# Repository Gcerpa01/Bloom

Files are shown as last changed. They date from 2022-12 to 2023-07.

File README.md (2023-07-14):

# Bloom
Current development of a BLE Application utilizing Swift UI. This app is meant to utilize the central manager to connect to an ESP32-C3 in order to control a strip of WS2812B lights alongside an ESP32 Devkit V1 and PCM5102.

# General Information
This project has been in the making for three years as an introduction to Arduino Microcontrollers, Bluetooth Low Energy, and Swift. We utilize the Bloom app in order to tell the ESP which mode we want the microcontroller to be in so that the lights display the desired animation. When in audio visualizer, we connect our audio source to an attached bluetooth receiver (ESP32 + PCM5102) to read the audio and the MSGEQ7 then divides the audio frequencies for the ESP32-C3 to create an audio visualizer using the connected LED lights. Additionally, we take use of the PCM5102's output jack to connect an external speaker to listen to the audio being played. 

# Demo
Demo (https://youtu.be/ml52ldNw_ss)

A timeline of my improvements and steps in this journey can be found [in this twitter thread] (https://twitter.com/PunaticGerry/status/1292268597901811712?s=20) as well as in this github repro.
**further information will be provided below**.
 
 ---
 ## Steps and Resources
  After having finished my [Blynk Audio Visualizer project](https://github.com/Gcerpa01/Blynk-Audio-Visualizer) I began to hit some issues during setup due to certain WiFis being locked by an additional user account(University Campus WiFi for instance), so I began to look for tutorials on utilizing BLE to control the arduino's mode as I would no longer to depend on any external factor besides the user's source device to communicate with the BLE module
  
### 1. Utilizing BLE

 #### Upgrading to ESP32-C3
 In an effort to make the circuit smaller as well as cheaper and more efficient, I moved over to an ESP32-C3. Rather than needing an Arduino Nano and an HM-10 module, we now only require 1 module, allowing us to have more memory for more commands and customization within our BLE app. The following tutorial proved useful in making this change:
1. [Random Nerds](https://randomnerdtutorials.com/esp32-bluetooth-low-energy-ble-arduino-ide/)

 #### Using an HM-10 Module
 I first began by following the following tutorials to learn how to communicate with an HM-10 BLE Module utilizing apps available in the app store such as LightBlue and BLE Scanner to communicate with the Arduino:
1. [Makers Portal](https://makersportal.com/blog/2019/10/14/bluetooth-module-with-arduino)
2. [Instructables](https://www.instructables.com/WS2812-controlled-with-Bluetooth-and-Arduino)
 
The finished code for the Arduino side can be found in the [**BLE_Arduino**](https://github.com/Gcerpa01/Bloom/tree/main/BLE_Arduino) folder. Please note that the color wheel feature is not compatible when using the HM-10 Module.
 
### 2. Communicating via an App
 Once I finished being able to communicate with the Arduino I then began to look for tutorials on writing BLE applications on iOS. The ones I found helpful were the following:
1. [Adafruit](https://learn.adafruit.com/build-a-bluetooth-app-using-swift-5/communication)
2. [JaredWolff](https://www.jaredwolff.com/the-ultimate-how-to-bluetooth-swift-with-hardware-in-20-minutes/)
3. [NovelBits Part 1](https://novelbits.io/intro-ble-mobile-development-ios/)
4. [NovelBits Part 2](https://novelbits.io/intro-ble-mobile-development-ios-part-2/)

 I do want to note that I ended up subscribing to NovelBits to follow their tutorial a bit more in depth in order to learn to properly connect and communicate with the HM-10 Module but I also added a few free tutorials I found online and listed them first in the list above.
 
Note: This step remained the same when moving to an ESP32-C3, witht the only changes requiring to change the UUID's of the device we are connecting to. 

### 3. Designing the App
 Once I got the fundamentals down, I then went into designing the application to both work and have a UI I myself am proud off and would think is user friendly. I actually started off from scratch in order to create proper Swift Views, Navigation, a Color Wheel(*Note: Not implemented yet on Arduino side*) and once the views were done, I then began implementing the functionality I learned in the previous step to have my UI have implemented functionality. I utilized the following tutorials in order to learn how to build the application:
 1. [Color Wheel - Priva 28](https://github.com/Priva28/SwiftUIColourWheel)
 2. [Custom Color Picker - Haipp](https://youtu.be/dPQM332JOWY)
 3. [Color Slider - Medium - Priva 28](https://priva28.medium.com/making-a-custom-slider-in-swiftui-db440cd6d88c)
 4. [The Complete Guide to NavigationView in SwiftUI - Paul Hudson](https://youtu.be/nA6Jo6YnL9g)
 5. [Building First SwiftUI App - Paul Hudson](https://www.youtube.com/watch?v=aP-SQXTtWhY)
 
 The art for the application was done using both available SF Symbols and Art I made(and am still working on). The files for the application can be found in the [**Bloom**](https://github.com/Gcerpa01/Bloom/tree/main/Bloom) and [**Bloom.xcodeproj**](https://github.com/Gcerpa01/Bloom/tree/main/Bloom.xcodeproj), requiring to have xcode in order to run the applications on your iOS device(currently not on the app store)
 
 ---
 # Schematic
  ## ESP32-C3
 As stated before, in an effort to modify the Arduino and HM-10 circuit, I switched over to an ESP32-C3 to have more memory and have less modules. Additionally, in sake of customizability I also utilized an additional ESP32 and PCM5102 in order to customize the bluetooth audio receiver by utilizing the [ESP32 A2DP Receiver Libaray](https://github.com/pschatzmann/ESP32-A2DP) allowing to create the receiver with an assigned name and output audio using the digital to audio converter chip(PCM5102) with it's included audio jack, while still being able to read the frequencies of the audio being played.
 
 Note: If music visualization is not desired, the ESP32,PCM5102,MSGEQ7 can be removed for a simple LED light controller
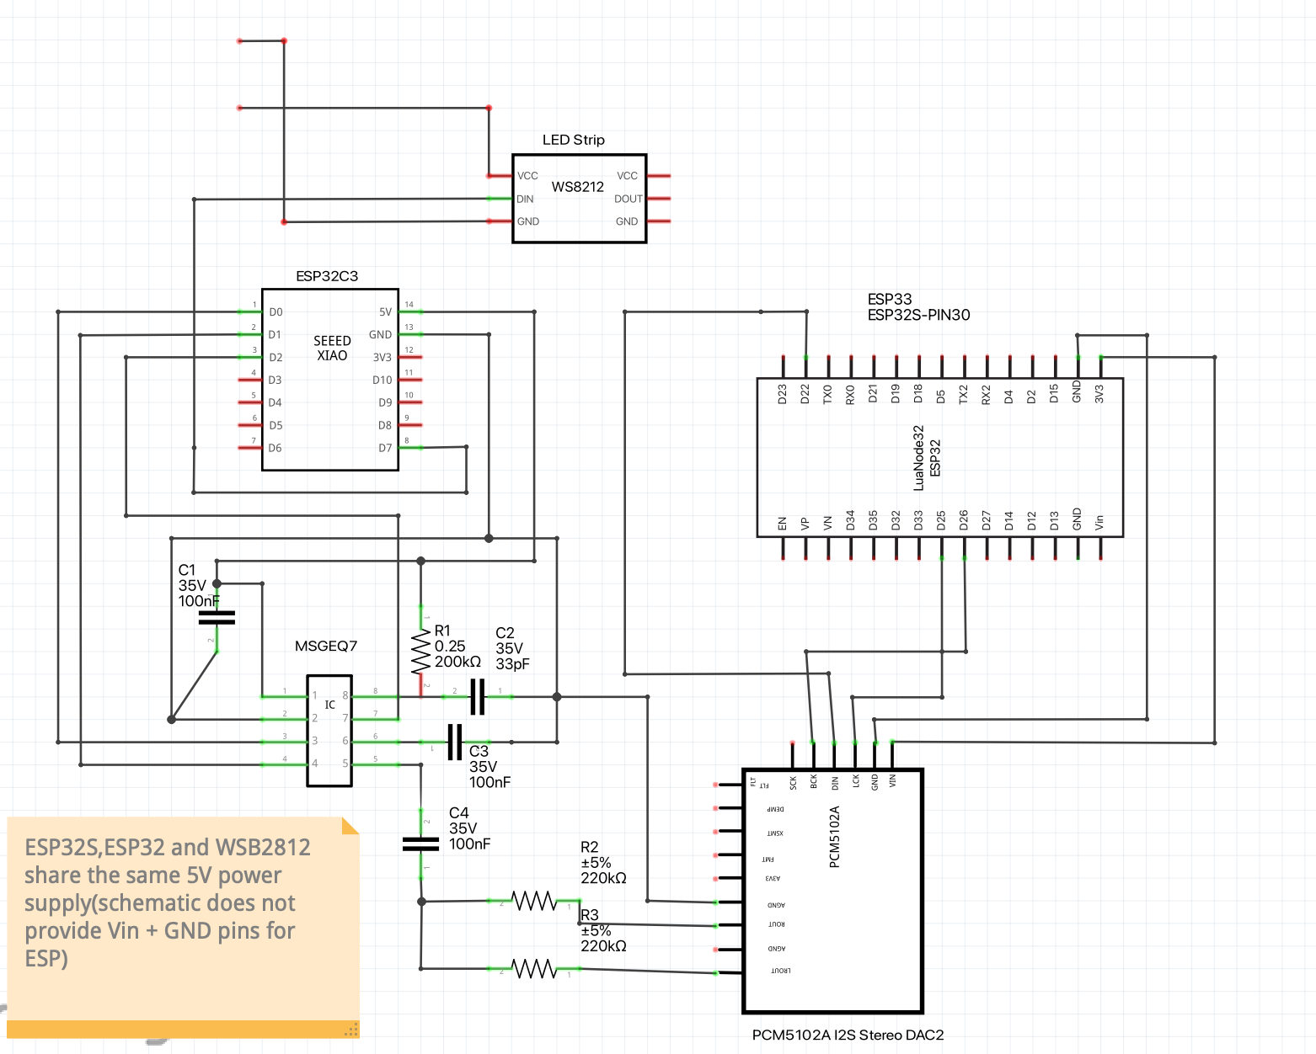
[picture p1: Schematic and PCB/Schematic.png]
New Modular
 
 
 ## Arduino and HM-10
For this project I modified my schematic from my [Blynk Audio Visualizer project](https://github.com/Gcerpa01/Blynk-Audio-Visualizer) to instead utilize an Arduino Nano and adding an HM-10 BLE module, with the final schematic appearing as below:

Untitled_Artwork

---
#### Caveats
 The project is at a point I'm happy calling it done despite it still needing a few upgrades. I need to work on some of the art for the buttons of the app, as well as enhance the code on the ESP32 side, as to have more animations avaiable in the app. Additionally, this code is exclusive to iOS at the moment given it was written for me and my family and friends to be able to utilize it so working on android alternative is a goal in the long run. 

---
#### Final Thoughts
 I began this project when I was in a dark spot in my life and I ended up finding a hobby I fell in love with. I have gone through multiple iterations for this project and despite it not being perfect it's at a state I am proud of what I have made and feel confident sharing it. I learned a lot about BLE, arduino, app development as well as coding but most importantly I learned about enjoying the journey and having fun with something. I do want to leave this repo updated and available as I want anyone learning or interested in learning these things to have access to this as a learning source.

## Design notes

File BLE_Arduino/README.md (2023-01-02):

# Bloom
Current development of a BLE Application utilizing Swift UI. This app is meant to utilize the central manager to connec to an HM-10 BLE module and an Arduino in order to control a strip of WS2812B lights

# General Information
This project has been in the making for two years as an introduction to Arduino Microcontrollers, Bluetooth Low Energy, and Swift. We utilize the Bloom app in order to tell the arduino which mode we want the microcontroller to be in so that the lights display the desired animation. When in audio visualizer, we connect our audio source to an attached bluetooth chip (MH-M28) to read the audio and the arduino then reads the audio frequencies to create an audio visualizer using the connected LED lights. Additionally, we take use of the MH-M28s' output jack to connect an external speaker to listen to the audio being played. 

A timeline of my improvements and steps in this journey can be found [in this twitter thread](https://twitter.com/PunaticGerry/status/1292268597901811712?s=20) and **further information will be provided below**.

 ***Videos of the final product can also be found in the twitter thread***
 
 ---
 ## Steps and Resources
  After having finished my [Blynk Audio Visualizer project](https://github.com/Gcerpa01/Blynk-Audio-Visualizer) I began to hit some issues during setup due to certain WiFis being locked by an additional user account(University Campus WiFi for instance), so I began to look for tutorials on utilizing BLE to control the arduino's mode as I would no longer to depend on any external factor besides the user's source device to communicate with the BLE module
  
### 1. Utilizing HM-10 Module
 I first began by following the following tutorials to learn how to communicate with an HM-10 BLE Module utilizing apps available in the app store such as LightBlue and BLE Scanner to communicate with the Arduino:
1. [Makers Portal](https://makersportal.com/blog/2019/10/14/bluetooth-module-with-arduino)
2. [Instructables](https://www.instructables.com/WS2812-controlled-with-Bluetooth-and-Arduino)
 
The finished code for the Arduino side can be found in the [**BLE_Arduino**](https://github.com/Gcerpa01/Bloom/tree/main/BLE_Arduino) folder 
 
### 2. Communicating via an App
 Once I finished being able to communicate with the Arduino I then began to look for tutorials on writing BLE applications on iOS. The ones I found helpful were the following:
1. [Adafruit](https://learn.adafruit.com/build-a-bluetooth-app-using-swift-5/communication)
2. [JaredWolff](https://www.jaredwolff.com/the-ultimate-how-to-bluetooth-swift-with-hardware-in-20-minutes/)
3. [NovelBits Part 1](https://novelbits.io/intro-ble-mobile-development-ios/)
4. [NovelBits Part 2](https://novelbits.io/intro-ble-mobile-development-ios-part-2/)

 I do want to note that I ended up subscribing to NovelBits to follow their tutorial a bit more in depth in order to learn to properly connect and communicate with the HM-10 Module but I also added a few free tutorials I found online and listed them first in the list above.

### 3. Designing the App
 Once I got the fundamentals down, I then went into designing the application to both work and have a UI I myself am proud off and would think is user friendly. I actually started off from scratch in order to create proper Swift Views, Navigation, a Color Wheel(*Note: Not implemented yet on Arduino side*) and once the views were done, I then began implementing the functionality I learned in the previous step to have my UI have implemented functionality. I utilized the following tutorials in order to learn how to build the application:
 1. [Color Wheel - Priva 28](https://github.com/Priva28/SwiftUIColourWheel)
 2. [Custom Color Picker - Haipp](https://youtu.be/dPQM332JOWY)
 3. [Color Slider - Medium - Priva 28](https://priva28.medium.com/making-a-custom-slider-in-swiftui-db440cd6d88c)
 4. [The Complete Guide to NavigationView in SwiftUI - Paul Hudson](https://youtu.be/nA6Jo6YnL9g)
 5. [Building First SwiftUI App - Paul Hudson](https://www.youtube.com/watch?v=aP-SQXTtWhY)
 
 The art for the application was done using both available SF Symbols and Art I made(and am still working on). The files for the application can be found in the [**Bloom**](https://github.com/Gcerpa01/Bloom/tree/main/Bloom) and [**Bloom.xcodeproj**](https://github.com/Gcerpa01/Bloom/tree/main/Bloom.xcodeproj), requiring to have xcode in order to run the applications on your iOS device(currently not on the app store)
 
 ---
 # Schematic
For this project I modified my schematic from my [Blynk Audio Visualizer project](https://github.com/Gcerpa01/Blynk-Audio-Visualizer) to instead utilize an Arduino Nano and adding an HM-10 BLE module, with the final schematic appearing as below:

Untitled_Artwork

---
#### Caveats
 The project is at a point I'm happy calling it done despite it still needing a few fixes. I need to work on some of the art for the buttons of the app, as well as enhance the code on the Arduino side, and perhaps switch to a different microcontroller as this code is currently unable to use all the animations I aimed for(hence them being grayed out via the application). Additionally, this code is exclusive to iOS at the moment given it was written for me and my family and friends to be able to utilize it so working on android alternative is a goal in the long run

---
#### Final Thoughts
 I began this project when I was in a dark spot in my life and I ended up finding a hobby I fell in love with. I have gone through multiple iterations for this project and despite it not being perfect it's at a state I am proud of what I have made and feel confident sharing it. I learned a lot about BLE, arduino, app development as well as coding but most importantly I learned about enjoying the journey and having fun with something. Hence even when I get the app on the app store I do want to leave this repo updated and available as I want anyone learning or interested in learning these things to have access to this as a learning source.

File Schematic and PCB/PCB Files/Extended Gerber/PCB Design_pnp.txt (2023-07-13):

*Pick And Place List
*Company=
*Author=
*eMail=
*
*Project=PCB Design
*Date=17:37:56
*CreatedBy=Fritzing 0.9.10b.2022-07-01.CD-2134-0-40d23c29
*
*
*Coordinates in mm, always center of component
*Origin 0/0=Lower left corner of PCB
*Rotation in degree (0-360, math. pos.)
*
*No;Value;Package;X;Y;Rotation;Side;Name
1;220k;THT;57.3159;-46.0543;90;Bottom;R2
2;;;28.1058;-6.68443;0;Bottom;Via23
3;;;79.6679;-22.9686;0;Top;GND1
4;100nF;100 mil [THT, multilayer];52.2359;-37.1643;-90;Bottom;C3
5;;;23.0258;-10.4944;0;Bottom;Via22
6;;;20.4858;-33.3543;0;Bottom;Via18
7;;;77.518;-39.8483;-90;Bottom;PCM5102A
8;100nF;100 mil [THT, multilayer];57.3159;-37.1643;-90;Bottom;C4
9;220k;THT;62.3959;-42.2443;90;Bottom;R3
10;200k;THT;42.0759;-37.1643;0;Bottom;R1
11;;;17.9458;-33.3543;0;Bottom;Via17
12;;;47.1558;-42.2443;0;Bottom;Via1
13;;;12.8658;-6.68443;0;Bottom;Via21
14;;;59.8558;-19.3844;0;Bottom;Via11
15;;;75.4935;-10.4875;90;Bottom;ESP32C3
16;;;34.4558;-9.22443;0;Bottom;Via9
17;;;31.9158;-33.3543;0;Bottom;Via7
18;;;9.05585;-11.7644;0;Bottom;Via3
19;;;59.8558;-27.0044;0;Bottom;Via10
20;;;24.2958;-51.1343;0;Bottom;Via16
21;;;34.4559;-5.41433;0;Top;Vin
22;;;17.9458;-51.1343;0;Bottom;Via15
23;;;40.8058;-11.7644;0;Bottom;Via19
24;;;73.4591;-22.9686;0;Top;Vin1
25;33pF;100 mil [THT, multilayer];44.6159;-39.7043;-180;Bottom;C2
26;;;14.8407;-26.6597;-90;Bottom;ESP32
27;;;36.9958;-16.8444;0;Bottom;Via2
28;100nF;100 mil [THT, multilayer];48.4259;-18.1143;0;Bottom;C1
29;;THT;50.9659;-28.2743;-90;Bottom;MSGEQ
30;;;36.9958;-1.60443;0;Bottom;Via20
31;;;30.6458;-23.1944;0;Bottom;Via14
32;;;45.6742;-54.3799;0;Top;Din
33;;;42.966;-54.3962;0;Top;Vin
34;;;38.2658;-20.6544;0;Bottom;Via12
35;;;40.8059;-5.41433;0;Top;GND
36;;;48.4258;-54.3799;0;Top;GND
37;;;40.8058;-23.1944;0;Bottom;Via13

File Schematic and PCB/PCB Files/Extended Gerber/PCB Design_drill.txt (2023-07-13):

; NON-PLATED HOLES START AT T1
; THROUGH (PLATED) HOLES START AT T100
M48
INCH
T100C0.038194
T101C0.030000
T102C0.038000
T103C0.035000
T104C0.015748
T105C0.035050
%
T100
X027871Y018838
X027871Y016877
X028065Y010131
X027871Y012877
X027871Y019877
X030065Y010131
X027871Y013877
X032065Y010131
X029065Y010131
X027871Y017877
X031065Y010131
X033064Y010131
X027871Y015877
X027871Y014878
X027871Y020878
T101
X017063Y015631
X022565Y015133
X022565Y014131
X020565Y015133
X019567Y007131
X020565Y014131
X018565Y007131
X018065Y015631
T102
X031565Y001131
X030565Y007136
X032565Y007136
X028565Y001131
X027565Y007136
X028565Y007136
X031565Y007136
X032565Y001131
X029565Y001131
X029565Y007136
X026565Y001131
X027565Y001131
X026565Y007136
X030565Y001131
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

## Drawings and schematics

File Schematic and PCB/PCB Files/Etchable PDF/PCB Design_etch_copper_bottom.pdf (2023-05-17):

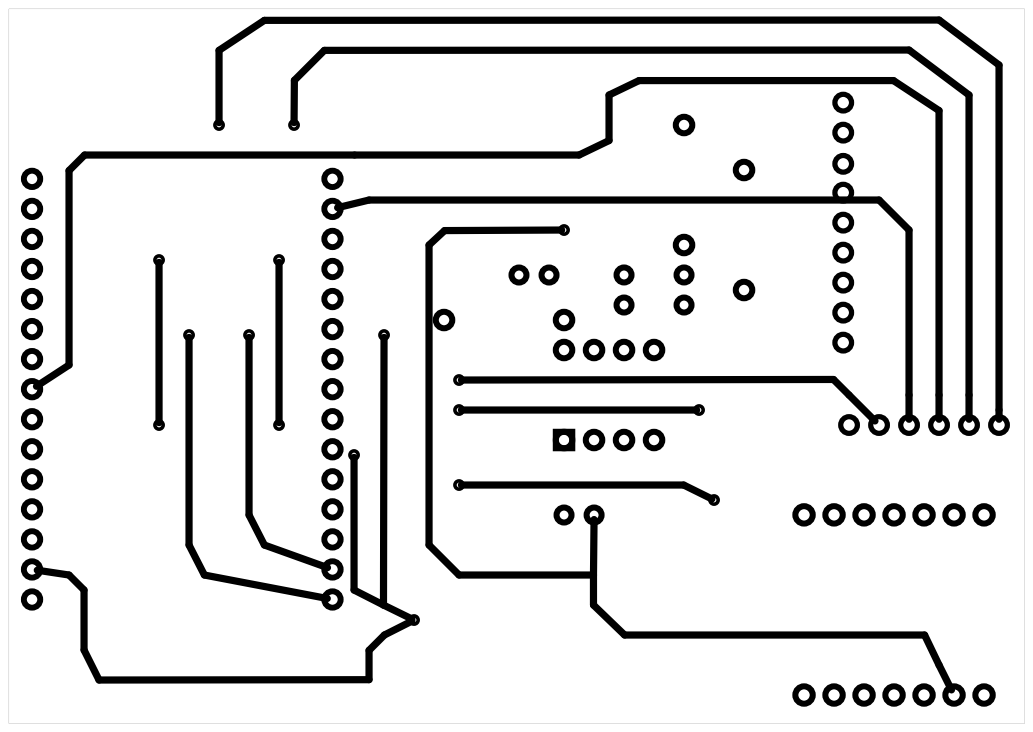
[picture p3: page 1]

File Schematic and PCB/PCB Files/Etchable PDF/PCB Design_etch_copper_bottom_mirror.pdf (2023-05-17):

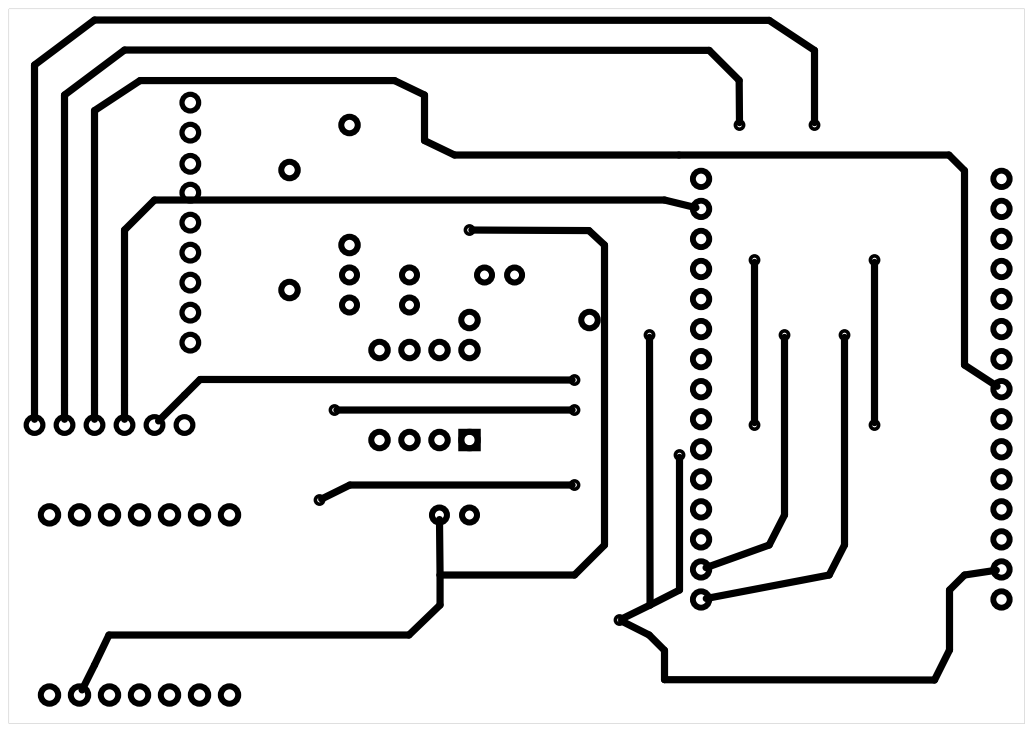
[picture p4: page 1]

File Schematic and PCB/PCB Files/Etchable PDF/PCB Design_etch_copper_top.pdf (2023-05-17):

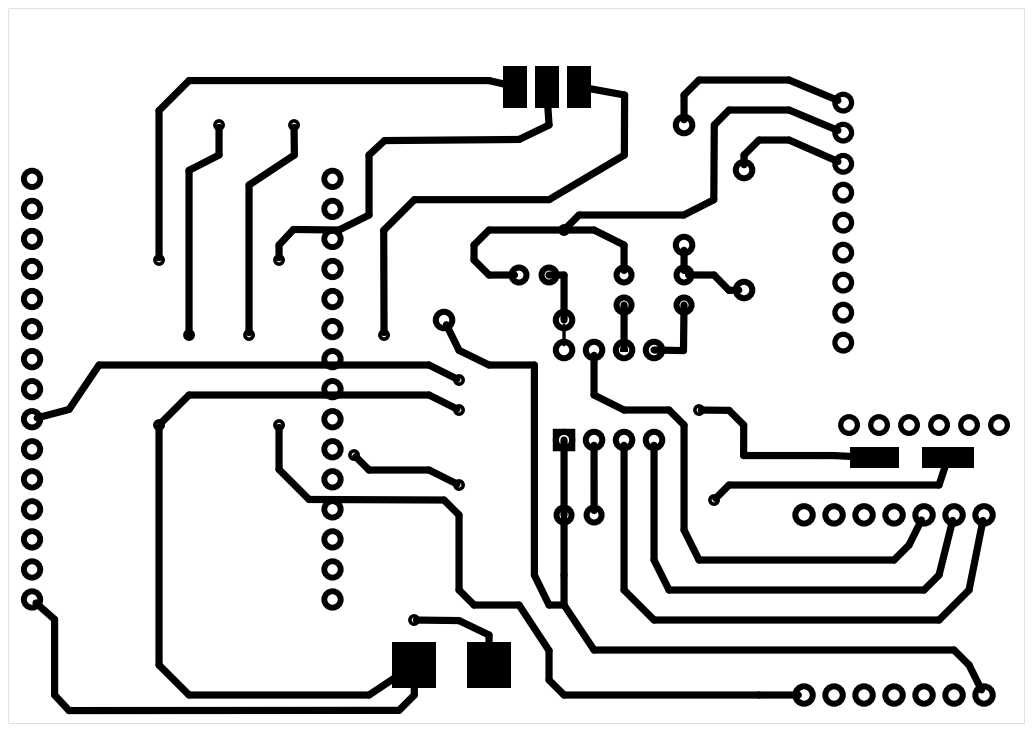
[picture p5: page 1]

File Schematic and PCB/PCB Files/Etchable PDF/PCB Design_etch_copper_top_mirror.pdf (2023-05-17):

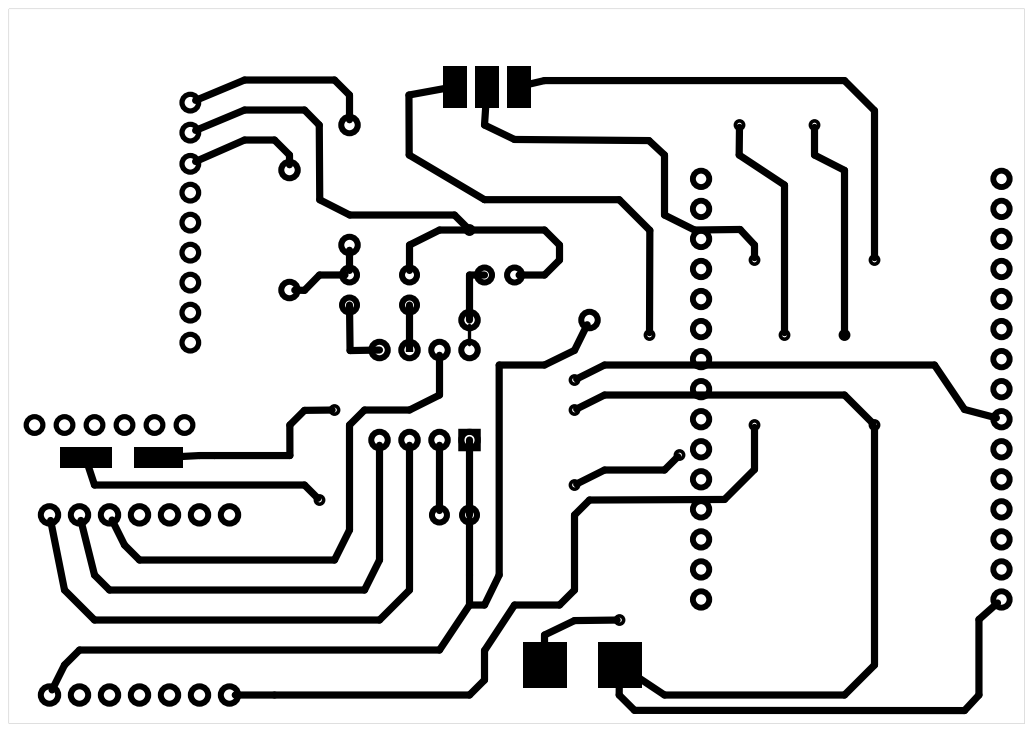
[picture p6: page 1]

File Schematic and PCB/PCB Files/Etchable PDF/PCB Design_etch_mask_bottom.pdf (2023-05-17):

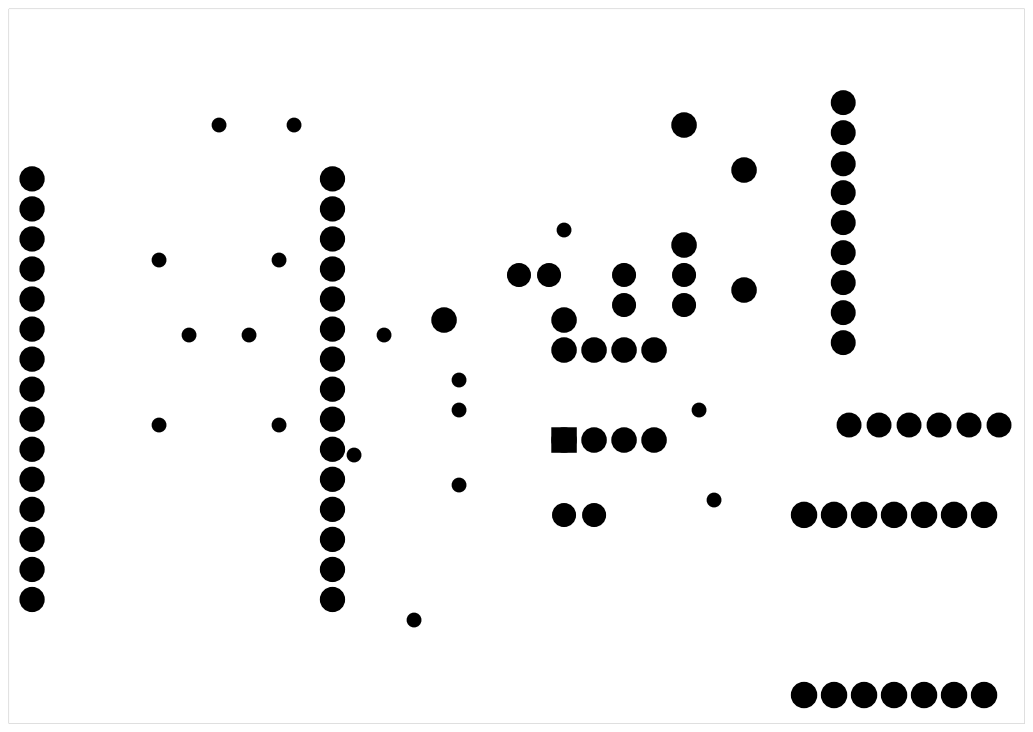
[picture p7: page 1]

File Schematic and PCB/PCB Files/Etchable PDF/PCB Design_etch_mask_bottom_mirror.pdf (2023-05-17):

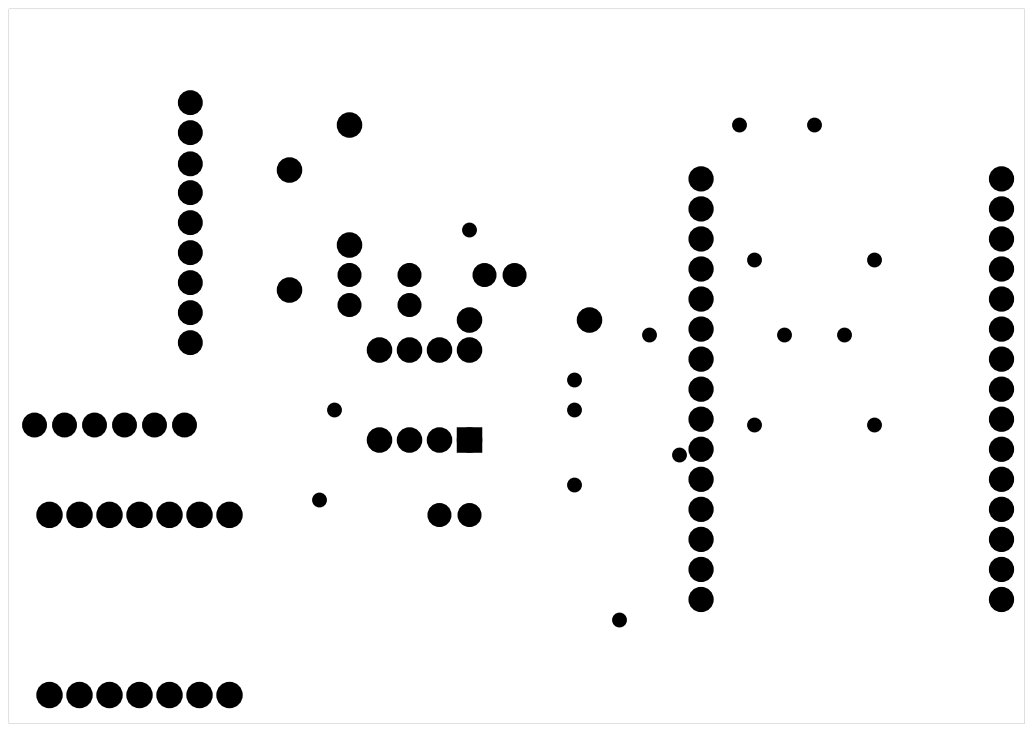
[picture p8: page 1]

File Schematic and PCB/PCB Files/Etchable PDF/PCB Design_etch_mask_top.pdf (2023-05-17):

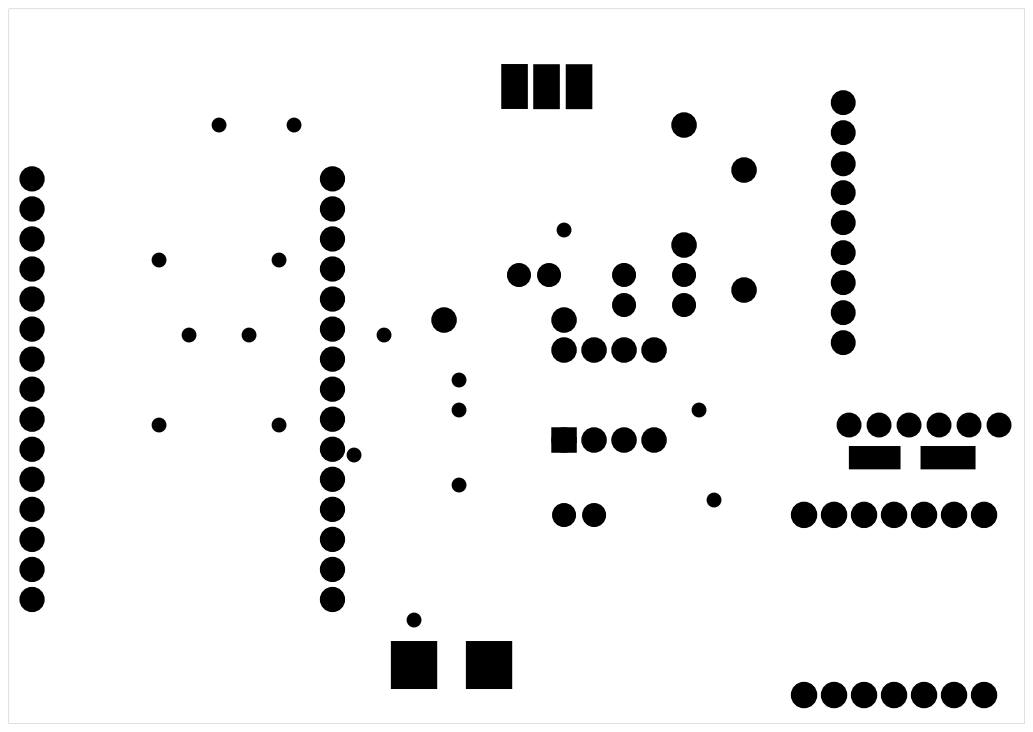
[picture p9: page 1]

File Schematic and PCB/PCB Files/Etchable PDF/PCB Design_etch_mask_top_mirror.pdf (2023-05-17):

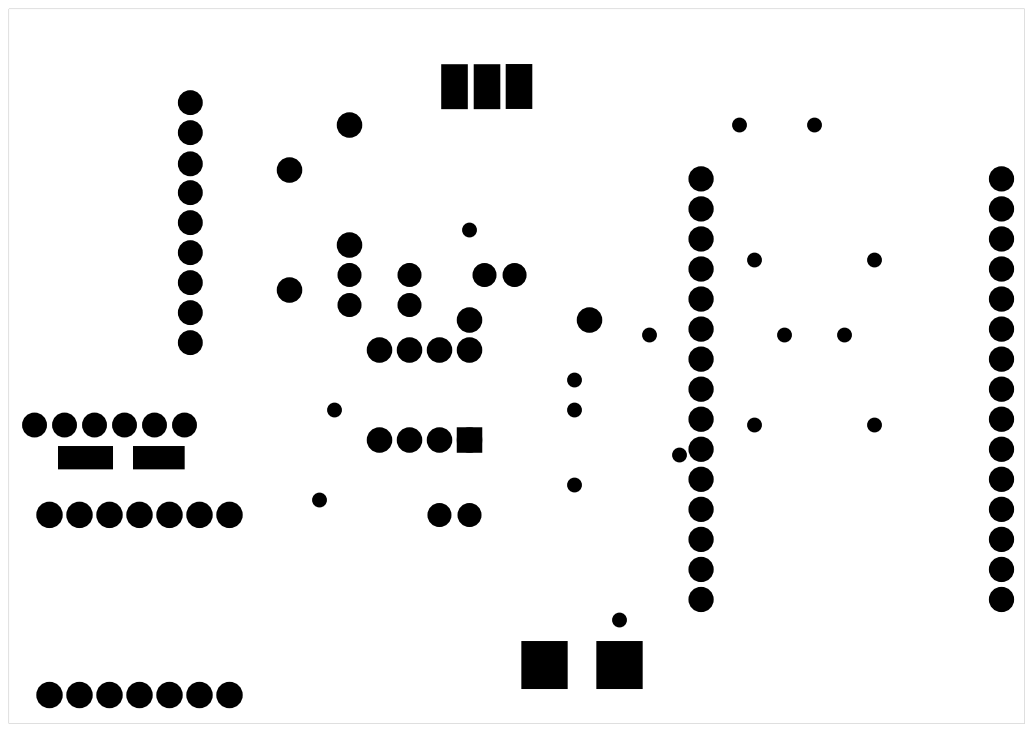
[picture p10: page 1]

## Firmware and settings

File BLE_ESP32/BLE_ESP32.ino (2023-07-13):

/* Gerardo Cerpa
 *
 * Utilized David Wang's code to read audio input from a 3.5 mm cable
 * so huge amount of gratitude to him.
 * The audio input is then used to animate an LED stip based
 * on the pitch and volume of the music.
 *
 *Also utilized Mark Wang's Pride 2015 animation, all credit goes to him
 *for that section of code and gratitude for an introduction
 *to LEDs
 *
 */

#include <FastLED.h>
#include "audioVisualizer.h"

/* -------------------------------- */
/*  ---------- BLE Control -------- */
/*  ------------------------------ */
#include <BLEDevice.h>
#include <BLEServer.h>
#include <BLEUtils.h>
#include <BLE2902.h>

char select_code[4] = "OFF";

/*  ------------------------------ */
/*  ------- Audio Visualizer ----- */
/*  ------------------------------ */
const int analogPin = A0; // MSGEQ7 OUT
const int strobePin = D1;  // MSGEQ7 STROBE 
const int resetPin = D2;   // MSGEQ7 RESET 
int spectrumValue[7];
// MSGEQ7 OUT pin produces values around 50-80
// when there is no input, so use this value to
// filter out a lot of the chaff.
int filterValue = 3000;
int brightness = 50;

/* -------------------------------- */
/*  ------- Control Variables ----- */
/*  ------------------------------ */
// Control variables to help dictate the mode running
int lightStatus = 0;
int colorWheelValues[3];
// Create led object
Color led;

/* -------------------------------- */
/*  ------- BLE Characteristics ----- */
/*  ------------------------------ */
BLEServer *pServer;
BLECharacteristic *pCharacteristic;

bool deviceConnected = false;
bool connectTimer = false;
unsigned long currentMillis, prevMillis = 0;
#define SERVICE_UUID "f56d1221-e24d-4b61-bbb6-cb8929f3a63b" // UART service UUID
#define LED_MODES_UUID "49360c8a-37b2-4fb8-b7f5-9957cb972fbc"
#define CHARACTERISTIC_UUID_TX "7afe65ae-976c-4a3a-84c1-8c33984019b7"
#define COLOR_WHEEL_UUID "325d04af-b205-4b96-a656-4ca6547159c8"

class MyServerCallbacks : public BLEServerCallbacks
{
 void onConnect(BLEServer *pServer)
 {
   if (!deviceConnected)
   {
     prevMillis = millis();
     connectTimer = true;
     Serial.println("Timer started to connect");
   }
   else
   {
     Serial.println("a device is already paired");
     ESP.restart();
   }
 };

 void onDisconnect(BLEServer *pServer)
 {
   deviceConnected = false;
   Serial.println("Device is not connected");
   pServer->startAdvertising(); // restart advertising after disconnecting
 }
};

class ControllerCallbacks : public BLECharacteristicCallbacks
{
 void onWrite(BLECharacteristic *pCharacteristic)
 {
   std::string commandReceived = pCharacteristic->getValue();

   if (commandReceived.length() > 0)
   {
     Serial.println("*********");
     Serial.print("Received Value: ");
     for (int i = 0; i < commandReceived.length(); i++)
     {
       Serial.print(commandReceived[i]);
     }
     Serial.println();

     if (!deviceConnected)
     {
       if (commandReceived.find("CC") != -1)
       {
         deviceConnected = true;
         connectTimer = false;
         Serial.println("Successfully paired");
       }
       else Serial.println("Incorrect");
     }
     else
     {

       // Do stuff based on the command received from the app
       if (commandReceived.find("OFF") != -1)
       {
         lightStatus = 0;
       }
       else if (commandReceived.find("WAV") != -1)
       {
         lightStatus = 1;
       }

       else if (commandReceived.find("PRD") != -1)
       {
         lightStatus = 2;
       }

       else if (commandReceived.find("SA1") != -1)
       {
         lightStatus = 3;
       }
     }

     Serial.println();
     Serial.println("*********");
   }
 }
};

class ColorWheelCallbacks : public BLECharacteristicCallbacks
{
 void onWrite(BLECharacteristic *pCharacteristic)
 {
   std::string commandReceived = pCharacteristic->getValue();
   if (deviceConnected)
   {
     lightStatus = 4;
     if (commandReceived.length() > 0)
     {
       Serial.println("*********");
       Serial.print("Received Value: ");
       for (int i = 0; i < commandReceived.length(); i++)
       {
         Serial.print(commandReceived[i]);
       }

       size_t string_pos = 0;
       size_t num_value = 0;
       while ((string_pos = commandReceived.find(",")) != std::string::npos)
       {
         colorWheelValues[num_value] = stoi(commandReceived.substr(0, string_pos));
         num_value += 1;
         commandReceived.erase(0, string_pos + 1);
       }

       colorWheelValues[2] = stoi(commandReceived.substr(0, string_pos));
//
//       Serial.print("Setting lights to ");
//       Serial.print(colorWheelValues[0]);
//       Serial.print(", ");
//       Serial.print(colorWheelValues[1]);
//       Serial.print(", ");
//       Serial.print(colorWheelValues[2]);
//       Serial.println(".");
     }
   }
   else
     Serial.println("Can't use,not connected");
 }
};

void setup()
{
  Serial.begin(9600);
  delay(100);

 // Create the BLE Device
 BLEDevice::init("Bloom"); // Give it a name

 // Create the BLE Server
 BLEServer *pServer = BLEDevice::createServer();
 pServer->setCallbacks(new MyServerCallbacks());

 // Create the BLE Service
 BLEService *pService = pServer->createService(SERVICE_UUID);

 // Create a BLE Characteristic
 pCharacteristic = pService->createCharacteristic(
     CHARACTERISTIC_UUID_TX,
     BLECharacteristic::PROPERTY_NOTIFY);

 pCharacteristic->addDescriptor(new BLE2902());

 BLECharacteristic *pCharacteristic = pService->createCharacteristic(
     LED_MODES_UUID,
     BLECharacteristic::PROPERTY_WRITE);

 BLECharacteristic *pCharacteristic2 = pService->createCharacteristic(
     COLOR_WHEEL_UUID,
     BLECharacteristic::PROPERTY_WRITE);

 pCharacteristic->setCallbacks(new ControllerCallbacks());
 pCharacteristic2->setCallbacks(new ColorWheelCallbacks());

 // Start the service
 pService->start();

 // Start advertising
 pServer->getAdvertising()->start();
 Serial.println("Waiting a client connection to notify...");

  /*  ------------------------------ */
  /*  -------- Set Up LEDS --------- */
  /*  ------------------------------ */
  led.ledSetup();

  /*  ------------------------------ */
  /*  ---- LED Visualizer Setup ---- */
  /*  ------------------------------ */
  // Setup the pins for reading from MSGEQ7
  randomSeed(analogRead(A0));
  // Read from MSGEQ7 OUT
  pinMode(analogPin, INPUT);
  // Write to MSGEQ7 STROBE and RESET
  pinMode(strobePin, OUTPUT);
  pinMode(resetPin, OUTPUT);
  // Set analogPin's reference voltage
  // analogReference(DEFAULT); // 5V

  // Set startup values for pins
  digitalWrite(resetPin, LOW);
  digitalWrite(strobePin, HIGH);
}

// Create an array of different methods to dictate the mode that will be
// running with the program
typedef void (*Spectremodes[])();
Spectremodes pos = {off, audio, pride, sparkle_AudioI, colorPicker};

void loop()
{
 if (connectTimer)
 {
   currentMillis = millis();
   if (currentMillis - prevMillis >= 9000)
   {
     Serial.println("Do not connect device");
     connectTimer = false;
     ESP.restart();
   }
 }
 if (deviceConnected)
 {
   pCharacteristic->setValue("Connected");
   pCharacteristic->notify();
 }
  pos[lightStatus]();
  // put your main code here, to run repeatedly:
}

// Runs the audio visualizer function to display
// an audio spectrum across the lights
void audio()
{
  Serial.println("AVI");

  digitalWrite(resetPin, HIGH);
  digitalWrite(resetPin, LOW);
  // Get all 7 spectrum values from the MSGEQ7
  for (int i = 0; i < 7; i++)
  {
    digitalWrite(strobePin, LOW);
    delayMicroseconds(30); // Allow output to settle

    spectrumValue[i] = analogRead(analogPin);

    // Constrain any value above 1023 or below filterValue
    spectrumValue[i] = constrain(spectrumValue[i], filterValue, 4000);

    // Remap the value to a number between 0 and 255
    spectrumValue[i] = map(spectrumValue[i], filterValue, 4000, 0, 255);

    // Remove serial stuff after debugging
//     Serial.print(spectrumValue[i]);
//     Serial.print(" ");
    digitalWrite(strobePin, HIGH);
  }
//  // Serial.println(""
  Color audioLights;
  audioLights.animate(spectrumValue);
}

// Turns all leds off
void off()
{
  Serial.println("Off");

  do
  {                                    // Start of a loop
    brightness = brightness - 10;      // Subtract 10 from the bright variable and save it
    FastLED.setBrightness(brightness); // Set LED strip Brightness to the value storged in "Bright"
    FastLED.show();                    // Update LED strip
    delay(10);                         // Wait for 10ms
  } while (brightness > 0);            // Go back to start of the loop if Bight is bigger then 0
  FastLED.clear();
  brightness = 50; // turn of LED strip
  FastLED.setBrightness(brightness);
  FastLED.show();
}

// Changes animation to sample provided in FastLED library
void pride()
{
  Color pride;
  pride.pridefx();
  Serial.println("Pride is on");
  FastLED.setBrightness(brightness);
  FastLED.show();
}

void sparkle_AudioI()
{
  digitalWrite(resetPin, HIGH);
  digitalWrite(resetPin, LOW);
  // Get all 7 spectrum values from the MSGEQ7
  for (int i = 0; i < 7; i++)
  {
    digitalWrite(strobePin, LOW);
    delayMicroseconds(30); // Allow output to settle

    spectrumValue[i] = analogRead(analogPin);
    // Constrain any value above 1023 or below filterValue
    spectrumValue[i] = constrain(spectrumValue[i], filterValue, 4000);

    // Remap the value to a number between 0 and 255
    spectrumValue[i] = map(spectrumValue[i], filterValue, 4000, 0, 255);

    // Remove serial stuff after debugging
//     Serial.print(spectrumValue[i]);
//     Serial.print(" ");
   digitalWrite(strobePin, HIGH);
  }
//  Serial.println("Sparkle");
  Color audioLights;
  audioLights.sparkleAudioI(spectrumValue);
}

// Change LEDs to user selected color
void colorPicker()
{
  Color colorPicker;
  colorPicker.customColor(colorWheelValues);
//  Serial.println("Reading user selected color");
}

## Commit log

2022-12-30 Runs with Arduino
2023-01-01 Pushing Files for Arduino
2023-03-20 Color Wheel only reverts to center when closed
    [BLE_Draft.ino]
2023-03-22 Fixed Color Wheel and Slider(do not communicate yet
2023-04-05 Edited Color Wheel Appearance
2023-04-24 Transitioning to ESP32C3
2023-05-15 Incorporated Color Wheel Picks
2023-05-17 Adding Files for PCB and Schematic
    [PCB Design.fzz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]
2023-05-17 Changed Pins in Arduino Files to match schematic
2023-07-13 Finalized V1.0
    [PCB Design.fzz, PCB Design2.fzz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]
